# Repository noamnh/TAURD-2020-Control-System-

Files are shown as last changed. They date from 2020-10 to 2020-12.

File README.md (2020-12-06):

# TAURD-2020-Control-System
TAU - formula student control system design
this control system include two nucleo micro controllers board which communicate each other via can
and transmit data between section and areas of the formula vehicle.
the main purpose is to transmit the pedal data from the front micro controller to the rear micro controller
the rear micro controller controls the thorttle position.
for making a robust and reliable a pcb board was design and prduced via eagle pcb cad.

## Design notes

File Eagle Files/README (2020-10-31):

This is the files of the pcb printed for this project

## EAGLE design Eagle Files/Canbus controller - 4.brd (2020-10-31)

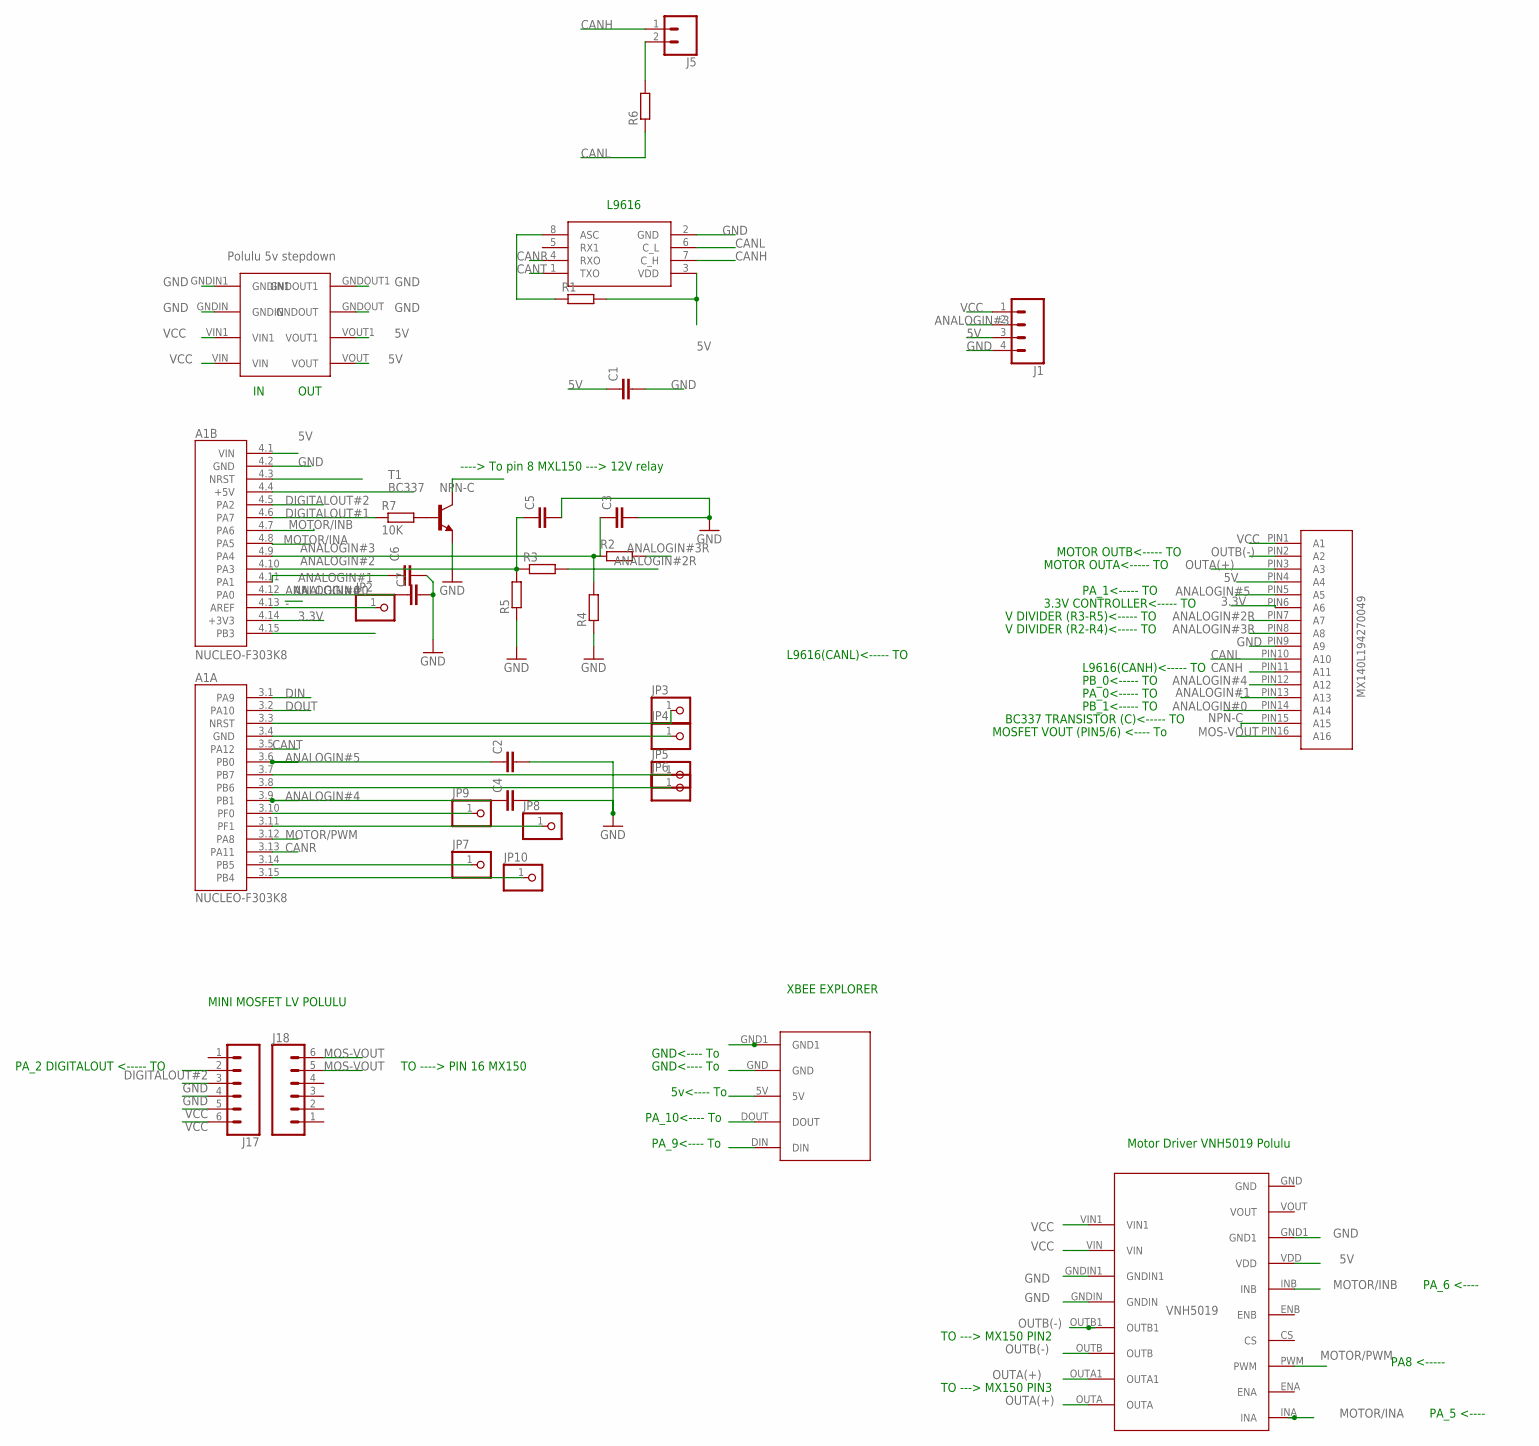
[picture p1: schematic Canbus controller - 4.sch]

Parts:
A1: NUCLEO-F303K8; MODULE_NUCLEO-F303K8
C1: C2,5-3; C2.5-3
C2, C3, C4, C5, C6, C7: C-EUC0805; C0805
J1: CONN_04POLAR; MOLEX-1X4
J5: CONN_02; 1X02
J17, J18: CONN_06NO_SILK_FEMALE_PTH; 1X06_NO_SILK
JP2, JP3, JP4, JP5, JP6, JP7, JP8, JP9, JP10: PINHD-1X1; 1X01
R1, R2, R3, R4, R5, R6: R-EU_0207/7; 0207/7
R7: 10K; 0207/7
T1: BC337; TO92
U$1: L9616; SO8
U$2: MX140L-194270049; MX150L-194270049
U$3: XBEEEXPLORER; XBEEREGULATED
U$4: VNH5019
U$5: 5VSTEPDOWN

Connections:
3.3V: A1.4.14 (+3V3), U$2.PIN6 (A6)
5V: A1.4.1 (VIN), C1.1, J1.3, R1.2, U$1.3 (VDD), U$2.PIN4 (A4), U$3.5V, U$4.VDD, U$5.VOUT, U$5.VOUT1
-: A1.4.13 (AREF), JP2.1
ANALOGIN#0: A1.4.12 (PA0), C7.1, U$2.PIN14 (A14)
ANALOGIN#1: A1.4.11 (PA1), C6.1, U$2.PIN13 (A13)
ANALOGIN#2: A1.4.10 (PA3), C5.1, R3.1, R5.2
ANALOGIN#2R: R3.2, U$2.PIN7 (A7)
ANALOGIN#3: A1.4.9 (PA4), C3.1, J1.2, R2.1, R4.2
ANALOGIN#3R: R2.2, U$2.PIN8 (A8)
ANALOGIN#4: A1.3.9 (PB1), C4.1, U$2.PIN12 (A12)
ANALOGIN#5: A1.3.6 (PB0), C2.1, U$2.PIN5 (A5)
CANH: J5.1, U$1.7 (C_H), U$2.PIN11 (A11)
CANL: R6.1, U$1.6 (C_L), U$2.PIN10 (A10)
CANR: A1.3.13 (PA11), U$1.4 (RXO)
CANT: A1.3.5 (PA12), U$1.1 (TXO)
DIGITALOUT#1: A1.4.6 (PA7), R7.1
DIGITALOUT#2: A1.4.5 (PA2), J17.2
DIN: A1.3.1 (PA9), U$3.DIN
DOUT: A1.3.2 (PA10), U$3.DOUT
GND: A1.4.2 (GND), C1.2, C2.2, C3.2, C4.2, C5.2, C6.2, C7.2, J1.4, J17.3, J17.4, R4.1, R5.1, T1.1 (E), U$1.2 (GND), U$2.PIN9 (A9), U$3.GND, U$3.GND1, U$4.GND1, U$4.GNDIN, U$4.GNDIN1, U$5.GNDIN, U$5.GNDIN1, U$5.GNDOUT, U$5.GNDOUT1
MOS-VOUT: J18.5, J18.6, U$2.PIN16 (A16)
MOTOR/INA: A1.4.8 (PA5), U$4.INA
MOTOR/INB: A1.4.7 (PA6), U$4.INB
MOTOR/PWM: A1.3.12 (PA8), U$4.PWM
unnamed: A1.3.3 (NRST), JP3.1
unnamed: R7.2, T1.2 (B)
unnamed: J5.2, R6.2
unnamed: R1.1, U$1.8 (ASC)
unnamed: A1.3.4 (GND), JP4.1
unnamed: A1.3.7 (PB7), JP5.1
unnamed: A1.3.8 (PB6), JP6.1
unnamed: A1.3.10 (PF0), JP9.1
unnamed: A1.3.11 (PF1), JP8.1
unnamed: A1.3.14 (PB5), JP7.1
unnamed: A1.3.15 (PB4), JP10.1
NPN-C: T1.3 (C), U$2.PIN15 (A15)
OUTA(+): U$2.PIN3 (A3), U$4.OUTA, U$4.OUTA1
OUTB(-): U$2.PIN2 (A2), U$4.OUTB, U$4.OUTB1
VCC: J1.1, J17.5, J17.6, U$2.PIN1 (A1), U$4.VIN, U$4.VIN1, U$5.VIN, U$5.VIN1

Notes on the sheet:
OUT
Motor Driver VNH5019 Polulu
PA8 <-----
PA_5 <----
PA_6 <----
MINI MOSFET LV POLULU
----> To pin 8 MXL150 ---> 12V relay
XBEE EXPLORER
PA_9<---- To
PA_10<---- To
5v<---- To
GND<---- To
MOSFET VOUT (PIN5/6) <---- To
BC337 TRANSISTOR (C)<----- TO
PB_1<----- TO
PA_0<----- TO
PB_0<----- TO
L9616(CANH)<----- TO
L9616(CANL)<----- TO
V DIVIDER (R2-R4)<----- TO
V DIVIDER (R3-R5)<----- TO
3.3V CONTROLLER<----- TO
PA_1<----- TO
MOTOR OUTA<----- TO
MOTOR OUTB<----- TO
PA_2 DIGITALOUT <----- TO
TO ----> PIN 16 MX150
TO ---> MX150 PIN3
TO ---> MX150 PIN2
L9616

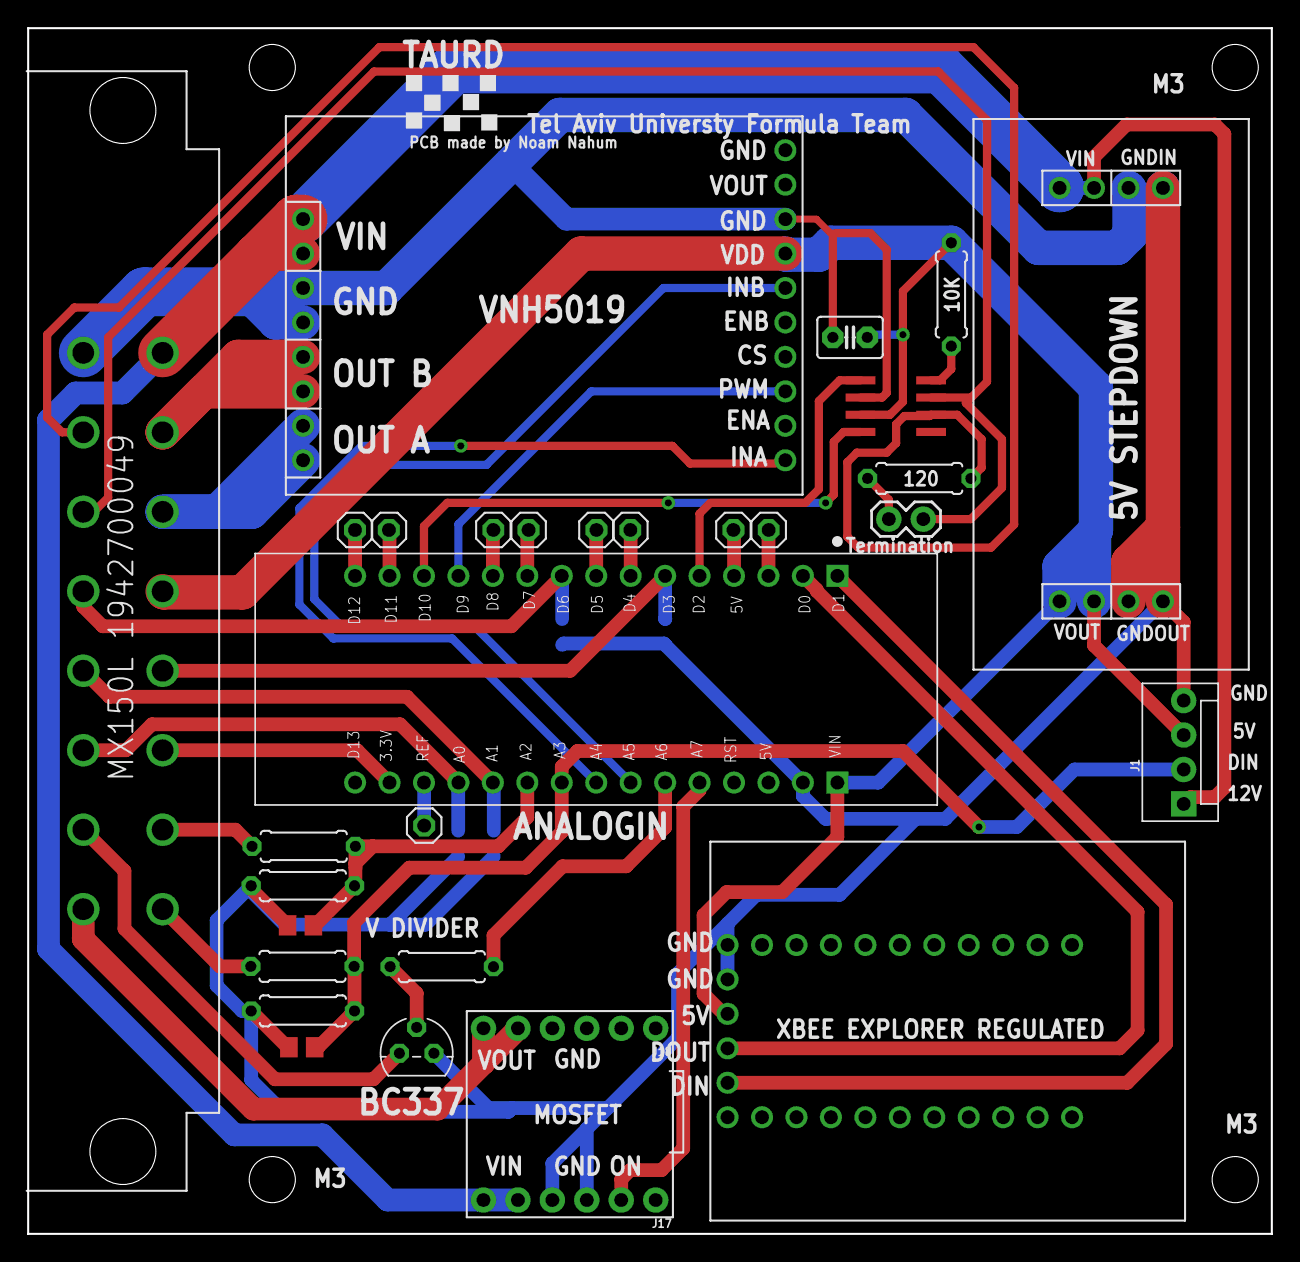
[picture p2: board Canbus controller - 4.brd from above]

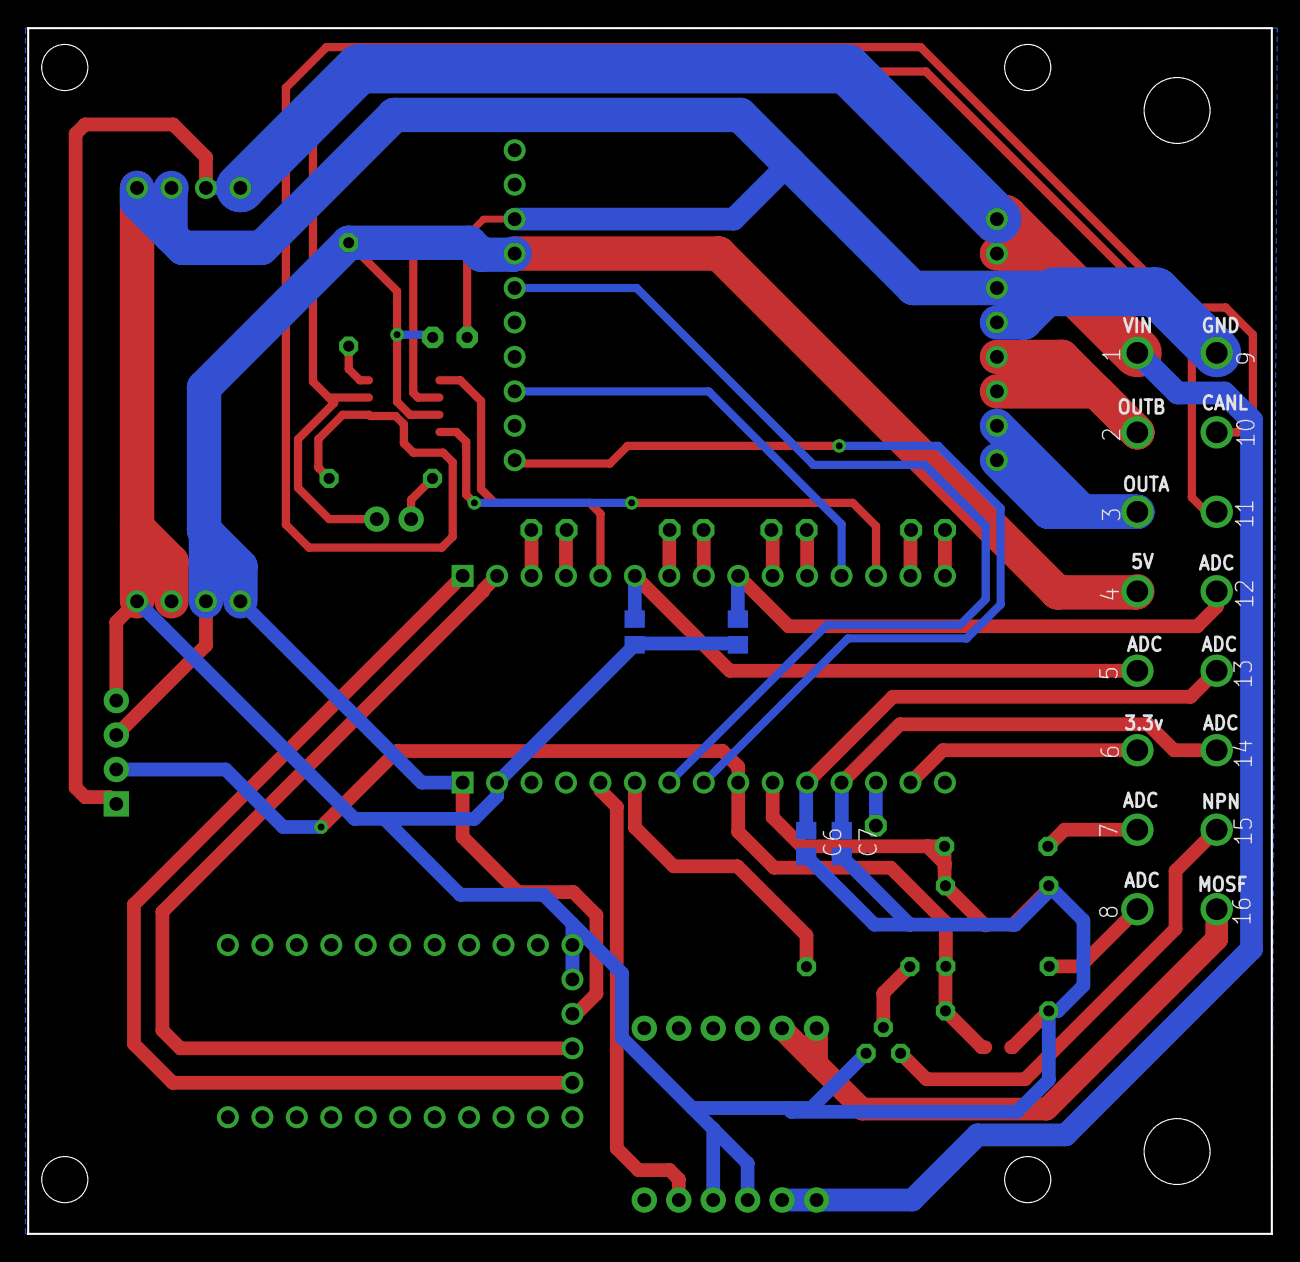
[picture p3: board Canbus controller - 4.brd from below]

Board: 2 copper layers, 91.7 x 88.9 mm, 34 parts (4 on the bottom side), 39 nets.

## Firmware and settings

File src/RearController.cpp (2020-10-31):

////////////////////////////////////////
//      Controlling Thorttle          //
//                                    //
////////////////////////////////////////

// Made by Noam Nahum & Dror Balbul Tel-Aviv University (Engineering Faculty) //

/*
    Pingout:
    Nucleo-L432KC
    A0 - PA_0 ---> Analogin ---> Read Potentiometer 1
    A1 - PA_1 ---> Analogin ---> Read Potentiometer 2
    A2 - PA_3 ---> Analogin ---> Volt Dvider (Optional)
    A3 - PA_4 ---> Analogin ---> Volt Dvider (Optional)
    A4 - PA_5 ---> Digitalout ---> Motor/in A = FWD direction
    A5 - PA_6 ---> Digitalout ---> Motor/in B = REV direction
    A6 - PA_7 ---> Digitalout ---> NPN Transistor for shutdown circuit
    A7 - PA_2 ---> Digitalout ---> To Brake MOSFET
    D10 - PA_11 ---> CANBUS TX
    D2 - PA_12 ----> CANBUS RX
    D9 - PA_8  ---> PWMOUT ---> to H bridge motor Driver
    D0 - PA_10 ---> SerialRX ---> Xbee DOUT 
    D1 - PA_9 ---> SerialTX ---> Xbee Din 
    
*/

///////////////
// Libraries //
///////////////

#include "PID.h" // pid library
#include "Motor.h" // Motor library
#include <Map.hpp> // Mapping library
#include "mbed.h" // Mbed library
#include "Sensor.h" // Sensor Reading and filtering library
#include "BufferedSerial.h"




///////////////
// #defines  //
//////////////

/////////////
// Objects //
/////////////

// ShutDown Fuel Transistor // 

DigitalOut ShutDown(PA_7);

/////Thorttle Potentiometers////

AnalogIn Sensor_1(PA_0);
AnalogIn Sensor_2(PA_1);

/////Motor Control////

Motor Thorttle(PA_8, PA_5, PA_6); // (pwm, inA, inB)

/////Serial - XBEE, PC////
Serial pc(SERIAL_TX, SERIAL_RX);
BufferedSerial XBEE(PA_9, PA_10);

//// CAN BUS communication ////
CAN CANBUS(PA_11, PA_12);

/////PID////

float Thorttledegree, Pedaldegree, Angle = 0;
//pid constants

const float kp = 1;
const float ki = 3;
const float kd = 0.0;
const float Ts = 0.001; // Time sample

//pid range

const float output_lower_limit = -255;
const float output_upper_limit = 255;

PID pid(&Pedaldegree, &Thorttledegree, &Angle, output_lower_limit, output_upper_limit, kp, ki, kd, Ts);

/////Sensor reading and filtering////

float Thorttle_1, Thorttle_2; // Thorttle Sensor 1 and 2 Initalizing
float weight = 0.05; // Expontetial filter weight
int Thorttle1, Thorttle2, Pedal1, Pedal2 = 0;
int countermsgdata = 0;


Sensor Thorttle_Sensors(&Thorttle_1, &Thorttle_2, &Thorttledegree,  weight);

/////Mapping////

Map Degree_to_speed = Map(-255,255,-1,1);

// Brake // 
//DigitalOut mybrake(PA_2);


//Tickers//
Ticker MainTicker;
Ticker SystemErrorTicker;

//Timers//
Timer CANTimer;

//Error Flags//
int  BrakeError, SystemError, BSPD = 0;
float ThorttleError, PedalError, CANError = 0;

//Data Packets//


// Functions//

void commandThorttle(){
    float Thorttlecommand = Degree_to_speed.Calculate(Angle);
    Thorttle.speed(Thorttlecommand);
    }
/*void BrakeOn(){
    mybrake = 1;
    Brake = 1;
    }
void BrakeOff(){
    mybrake = 0;
    Brake = 0;
    }*/

void SendError() {
    if (SystemError == 1){
        MainTicker.detach();
        pid.stop();
        SystemErrorTicker.attach(SendError, 0.0005);
        ShutDown = 0;
        }
    Thorttle.speed(-1);
}
void MainFunction() {
    Thorttle_1 = Sensor_1.read();
    Thorttle_2 = Sensor_2.read();
    if (Thorttle_Sensors.ErrorCheck()){
        ThorttleError = 1;
        SystemError = 1;
        SendError();
        }
    Thorttle_Sensors.ApplyFilter(Thorttle_Sensors.Sensor_Value_1());
    Thorttle1 = Thorttle_Sensors.Sensor_Value_1();
    Thorttle2 = Thorttle_Sensors.Sensor_Value_2();
    
    CANMessage msg;
    
        if(CANBUS.read(msg)) {
            if (CANTimer.read() > 0) {
                CANTimer.stop();
                CANTimer.reset();
                }
            if (msg.data[3]==1){
                //pc.printf("%d\n",1);
                PedalError = 1;
                SystemError = 1;
                SendError();
                }
            if (msg.data[3]==0){
                PedalError = 0;
                }
            if (msg.data[4]==1){
                //BrakeOn();
                }
            if (msg.data[4]==0){
                //BrakeOff();
                }
            Pedaldegree = msg.data[0];
            Pedal1 = msg.data[0];
            Pedal2 = msg.data[2];
            }
        if (!CANBUS.read(msg)) {
            CANTimer.start();
            }
        if (CANTimer.read() > 0.1) { // if message not recieved more then 0.1 sec send error
            CANTimer.stop();
            CANError = 1;
            SystemError = 1;
            SendError();
            }
        pid.sample();
        commandThorttle();
        countermsgdata++;
        }
        


int main(){
    XBEE.baud(115200);
    ShutDown = 1;
    pid.start();
    MainTicker.attach(MainFunction, 0.0005);
    while(1){
        /*if(Thorttle_Sensors.Sensor_Sub()>0.1){
            pc.printf("T1::%.4f\r\n", Thorttle_1);
            pc.printf("T2::%.4f\r\n", Thorttle_2);
            pc.printf("Sum::%.4f\r\n", Thorttle_Sensors.Sensor_Sum());
            pc.printf("Sub::%.4f\r\n", Thorttle_Sensors.Sensor_Sub());
            pc.printf("Timer::%.4f\r\n", Thorttle_Sensors.Sensor_timer());
            }*/
        /*pc.printf("P%.4f\n", Pedaldegree);
        pc.printf("M%.4f\n", Thorttledegree);
        pc.printf("C%.4f\n", CANError);
        pc.printf("T%.4f\n", ThorttleError);
        pc.printf("p%.4f\n", PedalError);*/
        XBEE.printf("P%.4f\n", Pedaldegree);
        XBEE.printf("M%.4f\n", Thorttledegree);
        XBEE.printf("C%.4f\n", CANError);
        XBEE.printf("T%.4f\n", ThorttleError);
        XBEE.printf("p%.4f\n", PedalError);
        
        //printf("0%d\n",Thorttle1);
            
        }
}

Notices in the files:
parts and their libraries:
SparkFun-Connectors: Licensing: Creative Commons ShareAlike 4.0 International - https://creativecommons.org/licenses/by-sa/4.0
